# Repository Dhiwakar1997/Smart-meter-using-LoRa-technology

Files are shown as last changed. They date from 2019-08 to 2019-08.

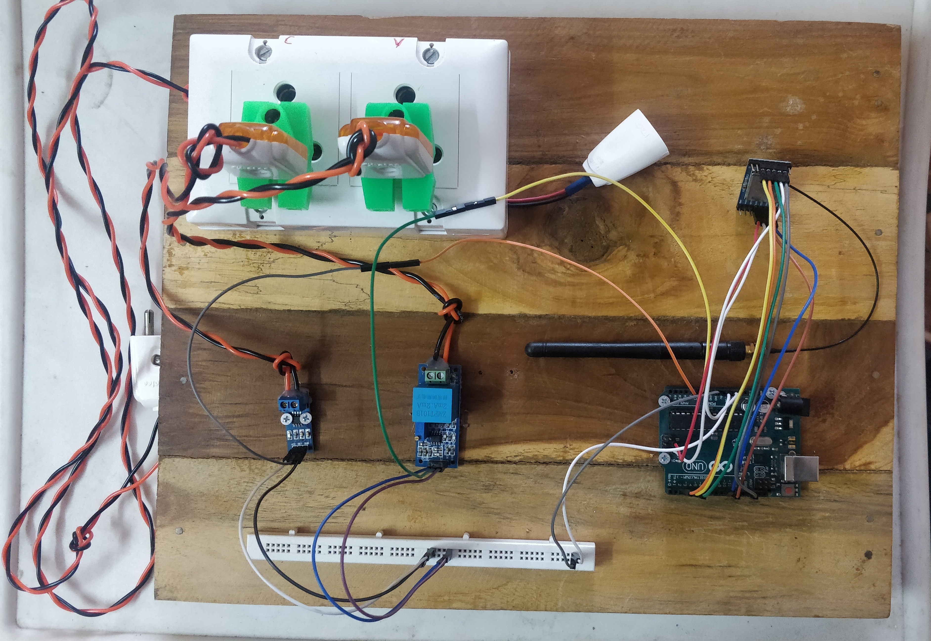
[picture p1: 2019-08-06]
implementation/LoRa based smart meter setup.jpg

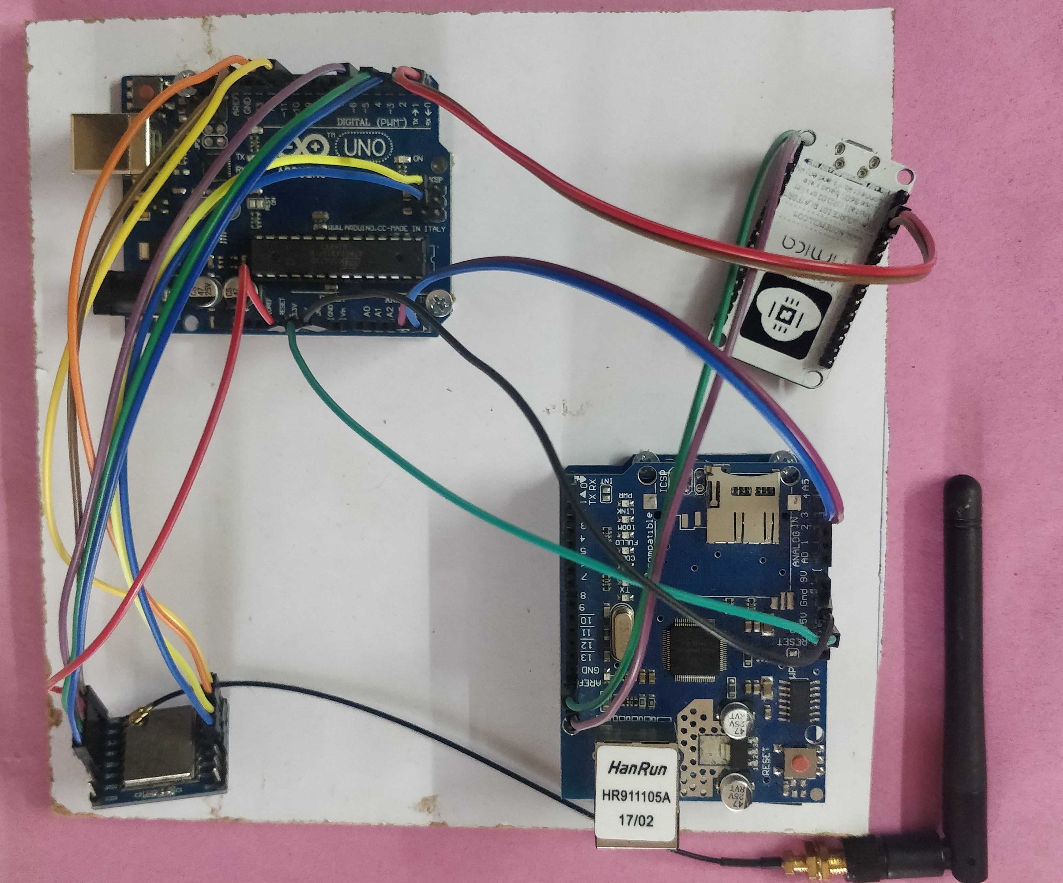
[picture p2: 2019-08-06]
implementation/gateway setup.jpg

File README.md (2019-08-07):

# Smart-meter-using-LoRa-technology
This is a smart energy meter project which measures the meter readings and visualizes the data live on a mobile application.
The main advantage of this project is that the project doesn't require an internet connection in the houses where the meter is installed.

Data is transferred wirelessly through LoRa wireless technology.

The project is divided into three phases:

1.LoRa based smart meter - It measures energy meter reading and transmits it wirelessly using LoRa.

2. LoRa receiver - It receives the LoRa signals form the meters.

3. Gateway with ethernet/Gateway with WiFi - Received data from LoRa receivers is transferred to a server through these gateways. 
                                             In this project two types of gateways are designed for flexibility,
                                             they are classified asGateway with ethernet & Gateway with WiFi.

Interfaces Used:
1.arduino is connected with LoRa transceivers using the SPI interface.

2. Arduino is connected to another Arduino using I2C interface.

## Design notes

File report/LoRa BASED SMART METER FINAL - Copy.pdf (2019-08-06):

# LoRa BASED SMART METER FOR RURAL AREAS WITHOUT INTERNET

## TABLE OF CONTENTS

TITLE | PAGE NO.
ABSTRACT | 7
LIST OF FIGURES | 8
LIST OF SYMBOLS | 9
1. INTRODUCTION | 10
1.1 CHAPTER INTRODUCTION | 10
1.2 INTRODUCTION TO LoRa BASED SMART METER | 10

FOR RURAL AREAS WITHOUT INTERNET

1.3 LITERATURE SURVEY | 11
1.4 SUMMARY | 14
2. INTERGRATION OF LoRa BASED SMART METER | 15

FOR REMOTE VILLAGES

2.1 CHAPTER INTRODUCTION | 15
2.2 NEED FOR LoRa BASED SMART METER IN | 15

REMOTE VILLAGE

2.3 IMPLEMENTATION OF LoRa BASED SMART | 16

METERS IN REMOTE VILLAGES

2.4 LoRa GATEWAY ENHANCEMENTS FOR REMOTE | 17

VILLAGES

2.5 ADVANTAGES OF LoRa BASED SMART METERS | 18

FOR REMOTE VILLAGES

2.6 SUMMARY | 18
3. HARDWARE IMPLEMENTATION OF SMART METER | 19
3.1 CHAPTER INTRODUCTION | 19
3.2 CONNECTION OF CT AND VT ACROSS THE LOAD | 20

3.3 SCHEMATIC DIAGRAM OF SMART ENERGY | 21

METER NODE

3.4 SCHEMATIC DIAGRAM OF GATEWAY USING | 23

ETHERNET

3.5 SCHEMATIC DIAGRAM OF GATEWAY USING Wi-Fi | 25
3.6 HARDWARE DESCRIPTION | 27
3.6.1 CURRENT SENSOR | 27
3.6.2 VOLTAGE SENSOR | 28
3.6.3 ARDUINO UNO | 30
3.6.4 ETHERNET SHIELD | 32
3.6.5 NODE MCU | 32
3.7 SUMMARY | 33
4. SOFTWARE IMPLEMENTATION | 34
4.1 CHAPTER INTRODUCTION | 34
4.2 SMART ENERGY METER NODE | 35
4.2.1 FLOWCHART | 35
4.2.2 ALGORITHM | 36
4.2.3 PROGRAM | 36
4.3 LoRa RECEIVER | 40
4.3.1 FLOWCHART | 40
4.3.2 ALGORITHM | 41
4.3.3 PROGRAM | 41
4.4 GATEWAY USING ETHERNET | 44
4.4.1 FLOWCHART | 44
4.4.2 ALGORITHM | 45
4.4.3 PROGRAM | 45
4.5 GATEWAY USING NODE MCU ESP8266 | 49

4.5.1 FLOWCHART | 49
4.5.2 ALGORITHM | 50
4.5.3 PROGRAM | 50
4.6 BLYNK MOBLIE APP | 55
4.7 SUMMARY | 56
5. CONCLUSION | 57
5.1 CHAPTERS OVERVIEW | 57
5.1.1 CHAPTER 1 OVERVIEW | 57
5.1.2 CHAPTER 2 OVERVIEW | 57
5.1.3 CHAPTER 3 OVERVIEW | 58
5.1.4 CHAPTER 4 OVERVIEW | 58
5.2 ENERGY METER MODULE | 59
5.3 LoRa GATEWAY MODULE | 60
5.4 FINAL CONCLUSION | 61
6. REFERENCE | 62

ABSTRACT

This project is all about creating a simple and effective way to transmit

the meter reading to the electricity board automatically by using IOT without any

intervention of humans. The project uses LoRa transceiver to transmit the data

from each house to the LoRa gateway from which the data is transmitted through

the internet to the electricity board server. This project is more cost effective than

any of the competitive projects on the same field. By automation of these energy

meters man power is saved in very large scale. By this project false reading can

be avoided. The LoRa transceivers used in this project has a very long range and

designed for transmitting small but essential data through long distance. The

smart meter consist of its own voltage and current sensors which will provide

essential data to calculate the power consumed by the consumer. This power data

is transmitted in real time to a LoRa gateway from which data is transmitted to

electricity board through internet. The main advantage of this project is the data

is transmitted in real time with lowest cost. The infrastructure developed for this

smart meter will open up opportunities for much wider industries to start. The

project can provide the infrastructure needed for government to monitor

electricity theft in future updates. In future updates using the same infrastructure,

location systems can be built as alternative for GPS in cities where these smart

meters are installed. This project is sponsored by IEDC

## LIST OF FIGURES

FIGURE NO. | DETAILS | PAGE NO.
2.1 | Block diagram of data flow | 17
3.1 | Connection of CT and VT | 20
3.2 | Smart energy meter node | 21
3.3 | Gateway using ethernet | 23
3.4 | Gateway using wi-fi | 25
3.5 | Current sensor | 27
3.6 | Pin diagram | 28
3.7 | Voltage sensor | 28
3.8 | Pin diagram | 29
3.9 | Arduino Uno | 30
3.10 | Ethernet shield | 32
3.11 | Node MCU | 33
4.1 | Flowchart of smart energy meter node | 35
4.2 | Flowchart of LoRa receiver | 40
4.3 | Flowchart of gateway using Ethernet | 44
4.4 | Flowchart of gateway using Node MCU | 49
4.5 | Mobile app screenshot | 55
5.1 | Energy meter module | 59
5.2 | Circuit box | 59
5.3 | LoRa gateway module | 60

## LIST OF SYMBOLS

SYMBOLS | EXPLANATION
V | Voltage
I | Ampere
W | power

## CHAPTER 1

INTRODUCTION

### 1.1 CHAPTER INTRODUCTION

This chapter gives a brief introduction about the LoRa technology used

in this project. This chapter explains about the main aim of the project and also

discuses about use of smart energy meters. Though this chapter a brief

explanation about the working of the LoRa based smart energy meter is

explained. In this chapter [1.3] literature survey displays few IEEE reference

papers. These reference papers provided required knowledge to build this project

“LoRa based smart meter for rural areas without internet”

### 1.2 INTRODUCTION TO LoRa BASED SMART METER FOR RURAL

AREAS WITHOUT INTERNET

The LoRa based smart meter is all about creating a simple and

effective way to transmit the meter reading from household energy meters to the

electricity board automatically by using IOT without any intervention of humans.

The project uses LoRa transceiver to transmit the data from each house to a LoRa

gateway from which the data is transmitted through internet to the electricity

board server. This project is more cost effective than any of the competitive

projects on the same field. By automation of these energy meters man power is

saved in a very large scale. By this project false readings can be avoided. The

LoRa transceivers used in this project has a very long range and designed for

transmitting small but essential data through long distance.

The smart meter consists of its own voltage and current sensors which

will provide essential data to calculate the power consumed by the consumer.

This power data is transmitted in real time to a LoRa gateway from which data is

transmitted to electricity board server through internet. The main advantage of this project is that the data is transmitted in real time with lowest cost. The project

can provide the infrastructure needed for government to monitor electricity theft

in future updates. In future, updates using the same infrastructure, location

systems can be built as alternative for GPS in cities where these smart meters are

installed.

### 1.3 LITERATURE SURVEY

Visalatchi Senthilnathan , Kamal Sandeep Karreddula (2017)

declare in their research that Energy theft is a very common problem in countries

like India where consumers of energy are increasing consistently as the

population increases. Utilities in electricity system are destroying the amounts of

revenue each year due to energy theft. The newly designed AMR used for energy

measurements reveal the concept and working of new automated power metering

system but this increased the Electricity theft forms administrative losses because

of not regular interval checkout at the consumer's residence. It is quite impossible

to check and solve out theft by going every customer's door to door. In this paper,

a new procedure is followed based on MICROCONTROLLER Atmega328P to

detect and control the energy meter from power theft and solve it by remotely

disconnect and reconnecting the service (line) of a particular consumer. An SMS

will be sent automatically to the utility central server through GSM module

whenever unauthorized activities detected and a separate message will send back

to the microcontroller in order to disconnect the unauthorized supply. A unique

method is implemented by interspersed the GSM feature into smart meters with

Solid state relay to deal with the non-technical losses, billing difficulties, and

voltage fluctuation complication.

Gunawan Wibisono, Gilang Permata Saktiaji, Ihsan Ibrahim (2017)

researched Traditional electricity meters read manually, large workloads, major

errors and distributed at different installation locations, need to spend a lot of time

and labor costs. In real-time, the accuracy and extension of the application cannot be fulfilled. With technological developments, electric meters now can be used

both ways, for real-time remote reading, and can be used as prepaid and postpaid,

making it smart meter. Currently the smart meter has become an important part

of the smart grid system. Therefore, the national power utility company (PLN)

Bali region decided to replace the existing meter with smart meter to support Bali

Eco Smart Grid. Long Range (LoRa) wide area network (WAN) is the access

technology that used for implementing smart meter because it has benefits

including can reach long distance, low power, and lower cost. This study aims to

analyze the techno economic smart meter 2 ways implementation at Bali region

by using techno-economic method and cost-benefit analysis. In addition to

analyze technological and economic aspects, the business model and the

regulatory aspect analysis are also included. The results show that LoRa WAN is

one of the technology options that can be used today, the business model that can

be used is build own or implementation is done by itself, build operate transfer

(BOT) or outsourcing to third party, and rental model. According the ministry of

communication and information regulation number 35/2015, LoRa WAN that

operate at frequencies 923-925 MHz can be implemented to support smart meter

implementation by Bali PLN.

Tian | Xia , (https://ieeexplore.ieee.org/author/37086562442) Cencen | Liu , (https://ieeexplore.ieee.org/author/37086563640) Xin | Zheng , (https://ieeexplore.ieee.org/author/37086557094) Ming | Lei , (https://ieeexplore.ieee.org/author/37086555833) Shangpeng
Wang , (https://ieeexplore.ieee.org/author/37086560597) Yingchun Wang,(2018) (https://ieeexplore.ieee.org/author/37086560953) developed | The principle of field testing for

digital electric energy meters is analyzed, according to which a digital reference

energy meter with high accuracy is developed based on high-precision frequency

division pulse output technology, algorithm of dot product sum of interpolation

re-sampling and high performance DSP. The test method based on the digital

reference meter is applied field testing comparing with a set of calibration system.

The results of the test prove high accuracy, efficiency and stability.

Win Hlaing ; (https://ieeexplore.ieee.org/author/37086219197) Somchai Thepphaeng ; (https://ieeexplore.ieee.org/author/37071208000) Varunyou Nontaboot ; (https://ieeexplore.ieee.org/author/37086216367)

Natthanan Tangsunantham ; (https://ieeexplore.ieee.org/author/37071583900) Tanayoot Sangsuwan ; (https://ieeexplore.ieee.org/author/37085398100) Chaiyod Pira (https://ieeexplore.ieee.org/author/37086223524) (2017)

propose that the advent of Internet and computational era, not only opportunity

to send and receive data between humans, but also among the devices without

human control over it. This is known as Internet of Things (IoTs) concept which

can be applied for solving the growing issue of power/energy management. A

solution is a cheap and easy to implement and manage energy monitoring system

for our daily usage of electric power. In order to overcome the human errors,

manual labor and cost reducing in energy consumption with more efficiency for

the power management system, in this paper, we focus mainly on IoT's energy

monitoring. The proposed design is to implement a very low cost wireless sensor

network and protocol for smart energy and web application capable of

automatically reading the unit and sending the data automatically for the power

users to view their current energy meter reading. By using this system, the users

will be aware of the electricity usage in his/her home to reduce the power wastage

and cost of consumption. The system consists of a digital energy meter, ESP8266

WiFi module and web applications for management system. The ESP8266 WiFi

module will be embedded into the meter and implement the TCP/IP protocol for

the communications between the meter and web application. The experimental

results show that the proposed system works very well with efficiency, and it is

feasible to implement in practical applications for very low cost-build automatic

energy meter reading.

### 1.4 SUMMARY

This chapter gives a introduction to LoRa based smart meter for

rural areas without internet. It gives a brief knowledge about the project and it

helps in understanding the aim of the project. It also provides IEEE paper of

reference in 1.3 literature survey. These reference paper helps to improve the

understanding about the project and also helps to relate the technologies used in

this project to that technologies used in the reference papers.

## CHAPTER 2

### 2. INTEGRATION OF LoRa BASED SMART METER

FOR REMOTE VILLAGES

### 2.1 CHAPTER INTRODUCTION

This chapter discusses about integration of LoRa based smart meters in

rural areas i.e. remote villages. In this chapter we have discussed about the need

for LoRa based smart meters in remote villages in 2.1 need for lora based smart

meters in remote villages. The explanation given about the need of this project in

this chapter is based on the real time day to day conditions. It speaks about the

reality conditions and also proposes solutions to handle that situation. In 2.2

implementation of lora based smart meters in remote villages the ways to

implement the lora based smart meter is discussed. The block diagrams were

used to explain about the data flow starting from household smart meter to a EB

server. In this chapter 2.3 implementation of lora based smart meters in remote

villages explains about the innovations made in LoRa gateway technologies in

this project. It clearly states the major advantages of the innovation in LoRa

gateway technology. Through this chapter the needs and ways to accomplish

though needs is discussed. This chapter gives clear knowledge about the

implementation and advantages of such implementation of this project.

### 2.2 NEED FOR LORA BASED SMART METERS IN REMOTE

VILLAGES

Technologies are for everyone. For people in urban cities and also for

people living in rural areas. But as of today, conditions changed as if smart

technologies are only applicable for people living in cities and people living in rural areas are meant to live old life style. The main reason behind this, is that

urban areas have updated infrastructures like high speed internet connections and

lot more infrastructure to make their life easier but in remote villages these

infrastructures are not available. This makes developers to concentrate more on

projects based on city life style.

One among those projects is smart meter working with internet

connections. But these smart meters cannot be installed in remote villages as these

villages doesn’t have internet connection for every house. LoRa based smart

meters take the advantage in this point. These LoRa based smart meters doesn’t

require internet connection in every house. As these LoRa transceivers have a

maximum range up to 10Km the energy meter readings can be directly

transmitted from a LoRa node i.e. LoRa based smart energy meter and it can be

received by a LoRa receiver in the LoRa gateway.

### 2.3 IMPLEMENTATION OF LORA BASED SMART METERS

IN REMOTE VILLAGES.

Each energy meter is provided with a LoRa transceivers. This energy

meter setup acts as a LoRa node. Each LoRa node transmits energy meter reading

with the unique address of that particular node encrypted inside a string. This

string is received by the LoRa gateway and the data is uploaded to a server using

internet. In this method its enough to have internet connection only for the

gateway alone and there is no need to provide internet connection for each and

every houses.

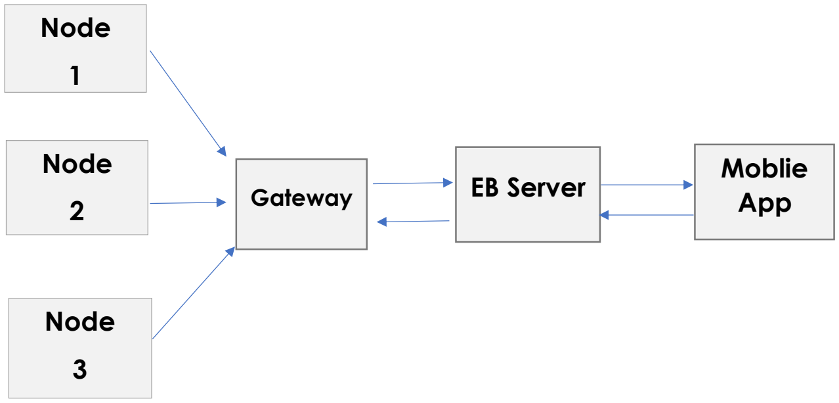
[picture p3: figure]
Node; Gateway; EB Server; Moblie; App

Fig 2.1 Block diagram of data flow

Node represents the smart energy meter fixed in every house. These

nodes are connected with LoRa gateway, and this gateway is connected to

internet. The gateways are programmed to receive energy meter readings from

the node and transmit to a EB server. This data can be retrieved from the server

and viewed using a mobile application. The mobile application receives the data

directly from the server.

### 2.4 LoRa GATEWAY ENHACEMENTS FOR REMOTE

VILLAGES

In general LoRa gateways are connected to internet using ethernet

cable. But when considering remote villages, even ethernet connections may not

be available in worst case scenarios. In this project we have come up with a

solution for this. The LoRa gateway that is designed for this project is compatible

with both ethernet cables as well as WiFi internet connections. The LoRa gateway

is connected to a WiFi module nodeMCU ESP8266 this enables LoRa gateway

to get connected with internet just with mobile hotspot connection. In real time

usage even a portable WiFi modem can be used to connect the LoRa gateway to

internet.

### 2.5 ADVANTAGES OF LoRa BASED SAMRT METERS FOR

REMOTE VILLAGES.

Illegal power tapping widely happen in remote villages. These illegal

power tapping can be easily identified using this LoRa based smart meter.

Every individual house is made accountable for their power usage as the whole

process is documented and digitalized. Form technical side, since villages

doesn’t have tall concrete walls and buildings to weaken the LoRa signal, in

these villages lesser number of gateways are enough to establish service when

compared to dense urban cities.

### 2.6 SUMMARY

This chapter discussed about the need for LoRa based smart meters in

remote villages. It also explained the implementation of LoRa based smart meters

in remote villages. The advantages of these smart meters specifically in remote

villages is detailly addressed here in this above chapter. This chapter also discuss

about the innovation made in LoRa gateway technology. It detailly informs about

the two major ways of implementation of LoRa gateway.

## CHAPTER 3

HARDWARE IMPLEMENTATION OF SMART METER

### 3.1 CHAPTER INTRODUCTION

This chapter discuss about the hardware implementation of smart meter. In

this chapter the circuit diagrams used in this project is detailly explained. These

circuit diagrams plays a major role in proper execution of this project. This

chapter is added with schematic diagrams with its explanations. These schematic

diagrams show cast the connections between the microcontrollers and other

sensors and transceivers. This would give a clear image about how the

components are connected with one another. These connections and explanations

also discus about the interface using which the components are connected with

one another. In this chapter each and every component used are explained in 3.5

hardware description. These details consist of key features of the components

with their specifications. By specifying the specification and key features of the

components knowledge about the nature of the components and their uses are

explained in this chapter.

### 3.1 CONNECTION OF CT AND VT ACROSS THE LOAD

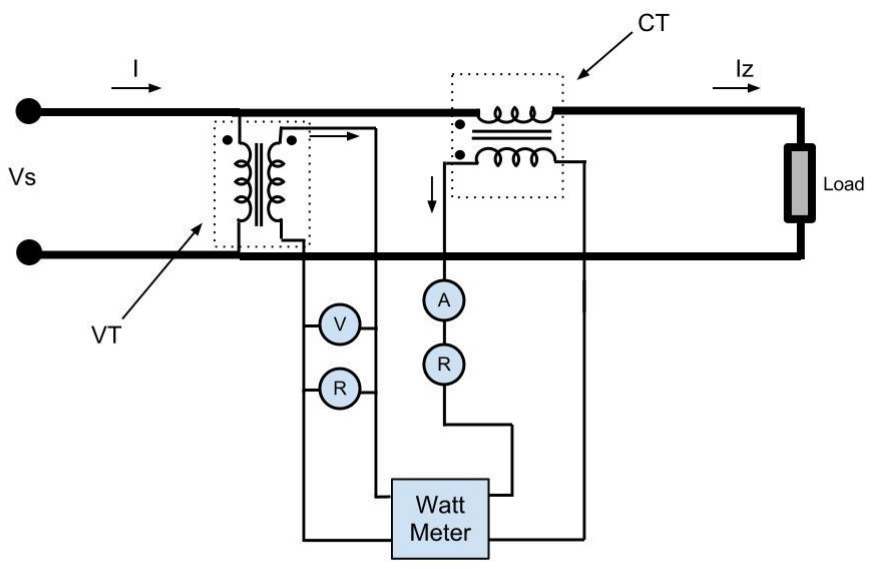
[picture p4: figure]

Fig 3.1 Connection of CT and VT

For transferring the power data value from each node there is a need to

measure the power data initially. For that purpose voltage and current are needed

to be measured. It is achieved by connecting the current sensor in series with load

and voltage sensor in parallel with load as described in circuit diagram. Here the

Arduino Uno acts as the wattmeter, which receives the sensor data from voltage

and current sensor and calculate watt and watt per hour data values.

### 3.2 SCHEMATIC DIAGRAM OF SMART ENERGY METER NODE

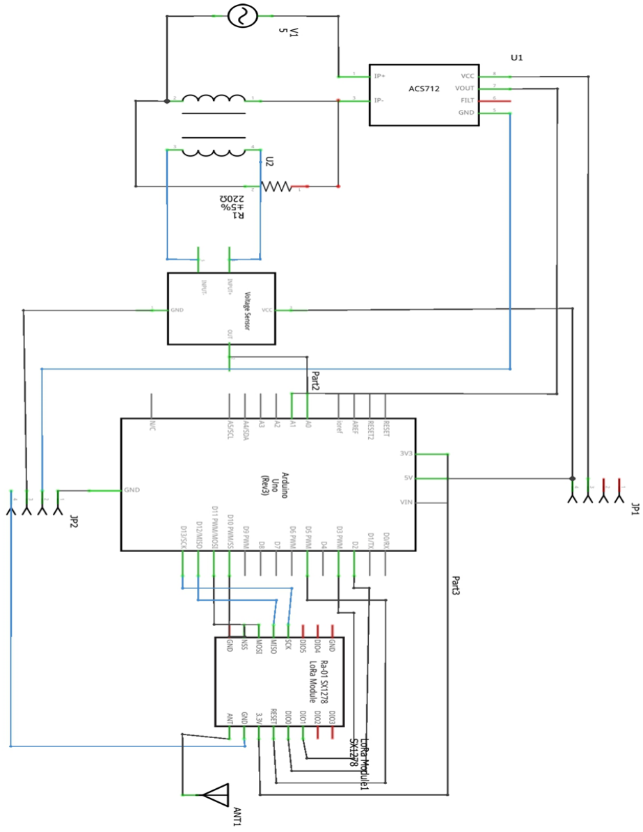
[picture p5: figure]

Fig 3.2 Smart energy meter node

EXPLANATION

In this phase energy meter is built and the microcontroller is

interfaced with the LoRa module SX1278. The schematic explains the way to

connect the current sensor ACS712 and voltage sensor across the load. The

voltage and current sensors are powered using +5 volt and Gnd of the Arduino

microcontroller. Two junctions are used to utilize the 5V and ground of the

Arduino to power multiple sensors connected to it. The voltage sensor is

connected to Analog pin A0 of the Arduino microcontroller. Current sensor is

connected to analog pin A1 of the Arduino microcontroller. The LoRa module

SX1278 is interfaced with Arduino microcontroller using Serial Peripheral

Interface (SPI). LoRa module is connected to an antenna of 5dB gain.

### 3.3 SCHEMATIC DIAGRAM OF GATEWAY USING ETHERNET

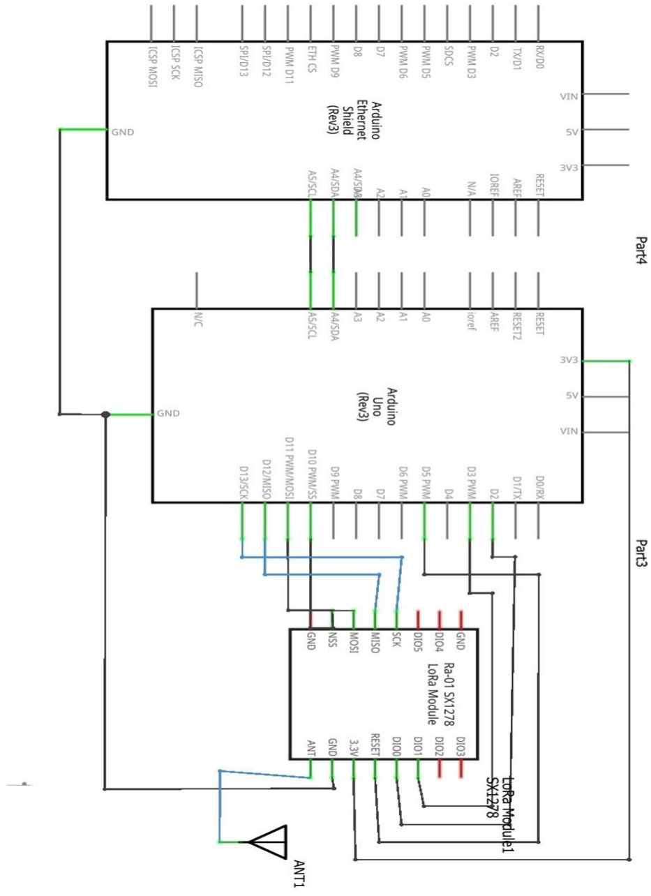
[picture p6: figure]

Fig 3.3 Gateway using ethernet

EXPLANATION

The schematic explains how the ethernet shield is connected to

LoRa receiver. The LoRa receiver by itself is connected to an Arduino Uno and

this Arduino is connected to an Ethernet shield using I2C interface. The LoRa

module SX1278 is interfaced with Arduino microcontroller using Serial

Peripheral Interface(SPI). LoRa module is connected to an antenna of 5dB gain.

The ethernet shield is connected to internet via fibre optic cables. The ethernet

shield is grounded through Arduino Uno. The LoRa module is powered by the

Arduino microcontroller.

### 3.5 SCHEMATIC DIAGRAM OF GATEWAY USING Wi-Fi

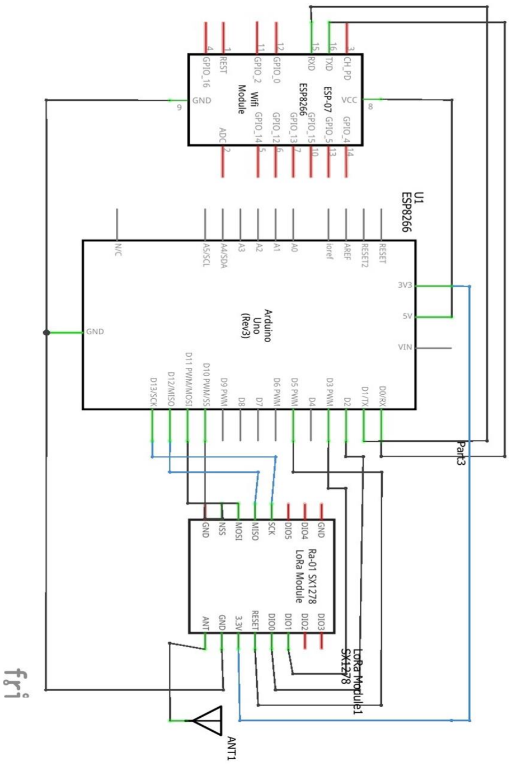
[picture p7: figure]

Fig 3.4 Gateway using wi-fi

EXPLANATION

The schematic explains how the node MCU ESP8266 is connected

to LoRa receiver. The LoRa receiver by itself is connected to an Arduino Uno

and this Arduino is connected to an node MCU ESP8266 using serial Tx and Rx

ports. The LoRa module SX1278 is interfaced with Arduino microcontroller

using Serial Peripheral Interface (SPI). LoRa module is connected to an antenna

of 5dB gain. The node MCU ESP8266 is connected to internet via Wi-Fi. The

node MCU ESP8266 is grounded through Arduino Uno. The LoRa module is

powered by the Arduino microcontroller.

### 3.6 HARDWARE DESCRIPTION

### 3.6.1 CURRENT SENSOR – ACS712

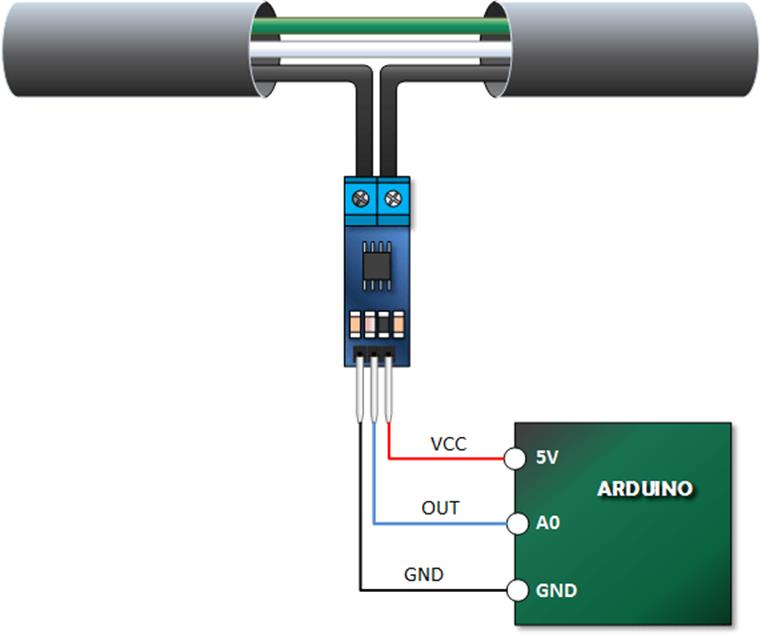
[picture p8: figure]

Fig 3.5 Current sensor

The Allegro® ACS712 provides economical and precise

solutions for AC or DC current sensing in industrial, automotive,

commercial, and communications systems. The device package allows for

easy implementation by the customer. Typical applications include motor

control, load detection and management, switched-mode power supplies,

and overcurrent fault protection.

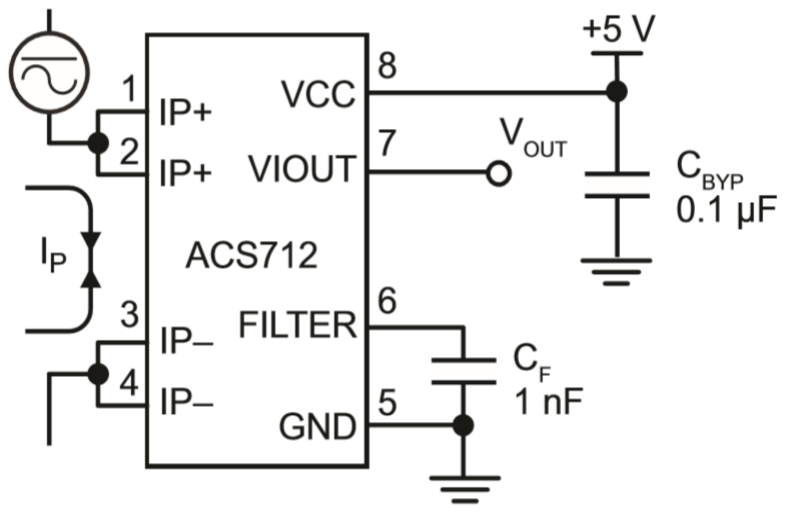
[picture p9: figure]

Fig 3.6 Pin diagram

KEY FEATURES

- Low-noise analog signal path
- Total output error 1.5% at TA = 25°C, and 4% at –40°C to 85°C
- 1.2 mΩ internal conductor resistance
- Output voltage proportional to AC or DC currents

Extremely stable output offset voltage

### 3.6.2 VOLTAGE SENSOR – ZMPT101B

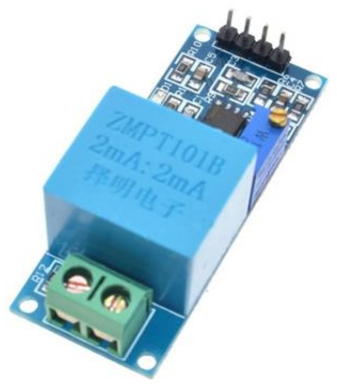
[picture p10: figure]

Fig 3.7 voltage sensor

ZMPT101B voltage sensor module is a voltage sensor made from the

ZMPT101B voltage transformer. It has high accuracy, good consistency for

voltage and power measurement and it can measure up to 250V AC. It is simple

to use and comes with a multi turn trim potentiometer for adjusting the ADC

output. The analysis in this paper tends to find more accurate relationship between

the input voltage and the ADC output by regression analysis. The ADC output is

adjusted using the trimpot to an appropriate value against a reference input.

Figure-1 is the ZMPT101B voltage sensor module.

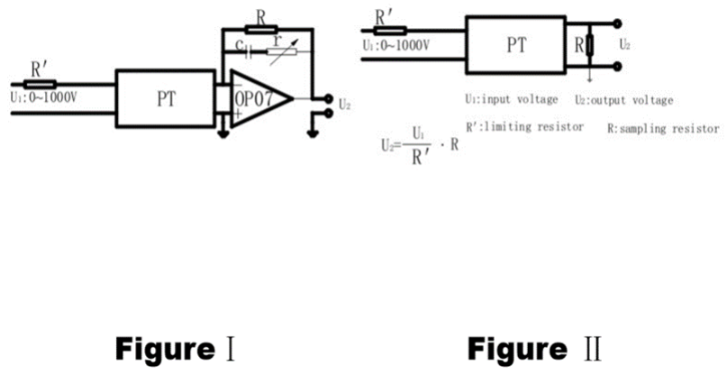
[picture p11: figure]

Fig 3.8 Pin diagram

KEY FEATURES

- Voltage upto 250 volts can be measured
- Light weight with on-board micro-precision voltage transformer
- High precision on-board op-amp circuit
- Operating temperature: 40ºC ~ + 70ºC
- Good consistency, for voltage and power measurement
- Very efficient and accuracy

### 3.6.3 ARDUINO UNO

The Arduino UNO is an open-source microcontroller board based

on the Microchip (https://en.wikipedia.org/wiki/Microchip_Technology) ATmega328P (https://en.wikipedia.org/wiki/ATmega328P) microcontroller and developed by

Arduino.cc. (https://en.wikipedia.org/wiki/Arduino) The board is equipped with sets of digital and analog

input/output (I/O) pins that may be interfaced to various expansion boards

(shields) and other circuits.

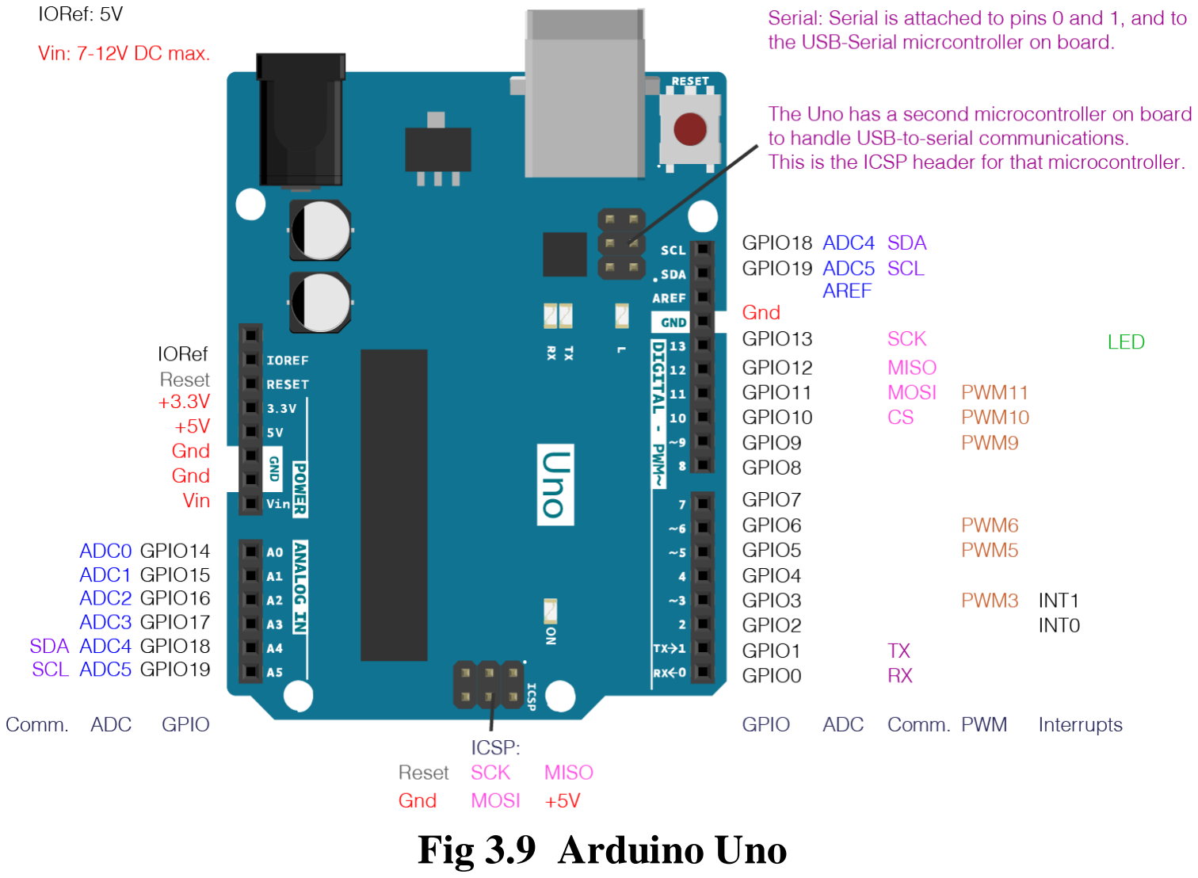
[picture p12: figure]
Fig 3.9 Arduino Uno

KEY FEATURES

- Microcontroller: ATmega328
- Operating Voltage: 5V
- Input Voltage (recommended): 7-12V
- Input Voltage (limits): 6-20V
- Digital I/O Pins: 14 (of which 6 provide PWM output)
- Analog Input Pins: 6

- DC Current per I/O Pin: 40 mA
- DC Current for 3.3V Pin: 50 mA
- Flash Memory: 32 KB of which 0.5 KB used by bootloader
- SRAM: 2 KB (ATmega328)
- EEPROM: 1 KB (ATmega328)
- Clock Speed: 16 MHz

The Arduino Uno is a microcontroller board based on the

ATmega328. Arduino is an open-source, prototyping platform and its

simplicity makes it ideal for hobbyists to use as well as professionals. The

Arduino Uno has 14 digital input/output pins (of which 6 can be used as

PWM outputs), 6 analog inputs, a 16 MHz crystal oscillator, a USB

connection, a power jack, an ICSP header, and a reset button. It contains

everything needed to support the microcontroller; simply connect it to a

computer with a USB cable or power it with a AC-to-DC adapter or battery

to get started.

### 3.6.4 ETHERNET SHIELD

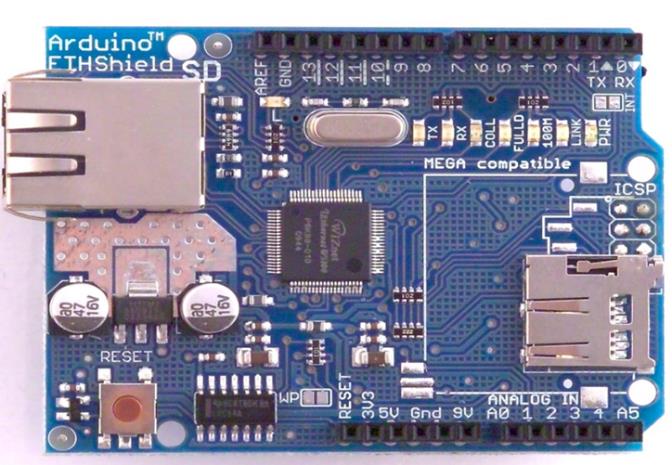
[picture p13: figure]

Fig 3.10 Ethernet shield

The ethernet shield is used to connect the Arduino Uno with

internet using fibre optic cables. It acts as the interface between Arduino

Uno and fibre optic cables.

### 3.6.5 NODE MCU ESP8266

The ESP8266 is a low cost MCU with built in Wi-Fi. It can be

paired with another host microcontroller, like an Arduino, to provide WiFi

networking | capability | for a | basic | IoT | development | platform.

Additionally, the ESP8266 can be used as a stand-alone MCU, as it

includes a 32-bit 80Mhz processor, 16 GPIO pins (4 PWM enabled) and a

built in Analog-to-Digital converter, SPI and I2C interfaces and more…

The MCU has a n operating voltage of 2.5V – 3.6V and average operating

current of 80 mA. Here is the official ESP8266 MCU datasheet (https://espressif.com/sites/default/files/documentation/0a-esp8266ex_datasheet_en.pdf) from the

Shangai -based manufacturer of the chip Express. The most popular

current version is the ESP-12E MCU pictured below. On its own this is not

very friendly for prototyping, as the spacing of the pins is not compatible

with standard headers and breadboards

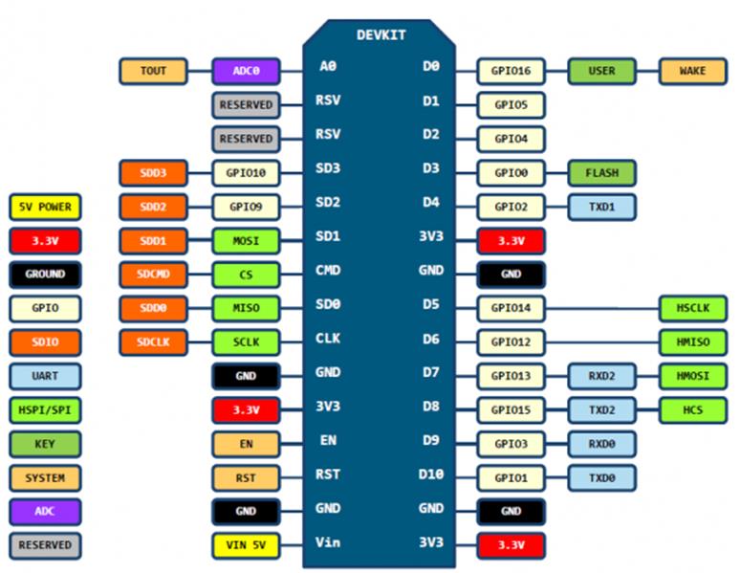
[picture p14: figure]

Fig 3.11 Node MCU

### 3.7 SUMMARY

This chapter clearly explained about the hardware

implementation and circuits used in this project. This chapter consists

of schematic diagrams and their explanations. The schematic diagrams

show casted in this chapter clearly explained the pin to pin connection

between the Arduino microcontroller and other sensors and

transceivers. In this chapter the hardware implementations and

executions are discussed. This chapter discussed about the hardware

specifications of each and every components used in this project. This

specifications included the use of these components. It also discussed

about the key feature of each and every components. Though this

chapter a clear image of hardware implementation and wider

awareness about the use of the components and their specifications.

## CHAPTER 4

SOFTWARE IMPLEMENTATION

### 4.1 CHAPTER INTRODUCTION

When the hardware components and their connections between them

describes physical portion of the project, the softwares used and code written in

the microcontroller plays the digital part of the project. This software portion acts

as important part of the project. The software codeing written in microcontroller

is what makes the functions to be performed. To transmit or receive data using

LoRa as well as calculating power all of this is carried out only by programming

the microcontroller respectively.

The software used to code the microcontroller is Arduino IDE. It

uses ‘C++’ programming language to program the microcontroller. This chapter

consists flowcharts, algorithms and as well as programs. The flowchart is the

diagrammatic representation of the flow of the program. This chapter consists of

4 flowcharts which represents 4 different programs used in the project. Algorithm

are included in this chapter. These algorithms are used to explain the flowcharts.

Thus for the four flowcharts included in the project four respective algorithms are

included to explain these flowcharts.

The ‘C++’ programs are included in this chapter. As the

programs play a very important role in the working of the project it is included.

The programs are written with comment by the side of every important lines.

These comment lines are used for understanding the program

### 4.2 SMART ENERGY METER NODE

### 4.2.1 FLOWCHART

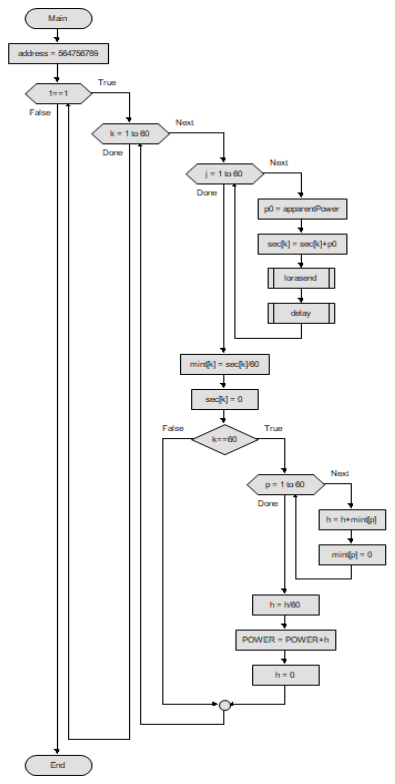
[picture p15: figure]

Fig 4.1 Flowchart of smart energy meter node

### 4.2.2 ALGORITHM

Step 1: Start.
Step 2: Create variables.
Step 3: Start of while loop.
Step 4: Start a for loop ‘k’ that increment every one minute for one hour and

Restart every hour.

step 5: Start a for loop ‘j’ that increment every one second for one minute and

restarts every minute.

Step 6: Calculates power value for that particular instance.
Step 7: Sum up the power values for one minute and store in a variable.
Step 8: Transmit the power value wirelessly through LoRa transceiver.
Step 9: Make delay for few milliseconds.
Step 10: Find the power value average and store it in a variable.
Step 11: If the for loop ‘k’ value is equal to ‘60’ continue else jump to step 4.
Step 12: Calculate watt/ hour value once an hour.
Step 13: Go to step 4.
Step 15: When for loop k terminates the command goes to while loop which is

infinite loop and program starts to run from step 4 again.

### 4.2.3 PROGRAM

#include <SPI.h> // 34rduino spi library

#include <LoRa.h> // 34rduino libraries ra02 lora

#include “EmonLib.h” | // Include Emon Library

EnergyMonitor emon1; | // Create an instance

float v=0;

float i=0;

float POWER=0,p0,h,sec[100],mint[100];

int counter=0,f=0;

char address[10]=”564756789”;

long start,esp;

void setup() {

Serial.begin(9600);

emon1.voltage(0, 380, 1.7); // Voltage: input pin, calibration, phase_shift

emon1.current(1, 10.8); // Current: input pin, calibration.

While (!Serial);

Serial.println(“LoRa Sender”);

if (!LoRa.begin(433E6)) {

Serial.println(“Starting LoRa failed!”);

while (1);

}

LoRa.setSpreadingFactor(10);

LoRa.setSignalBandwidth(62.5E3);

LoRa.crc();// put your setup code here, to run once

}

void loop() {

for(int k=1;k<=60;k++) // This loop increments every one minute

{

for(int j=1;j<=60;j++) // This loop increments every second

{

emon1.calcVI(20,2000); //POWER CALCULATION

float apparentPower = emon1.apparentPower; // deriving power value

p0=apparentPower;

if(p0<8)

p0=0;

sec[k]=sec[k]+p0; //sum up power value of every second for one minute

Serial.print(“Sending packet:”);// used for displaying the values

Serial.println(counter);

Serial.println(“power:”);

Serial.println(p0);

LoRa.beginPacket(); //LORA transnmission start

LoRa.print(POWER);

LoRa.print(‘$’);

LoRa.print(address);

LoRa.print(‘=’);

LoRa.print(p0);

LoRa.endPacket(); //LORA transmission end

counter++;

if(f==0)

{

delay(601); //delay for 601 millisecond

}

else

{

delay(592); // delay for 592 millisecond

f=0;

}

}

mint[k]=sec[k]/60; //takes average of power of one minute,stores in mint[k]

sec[k]=0; // set “sec[k]” to zero to make it empty for next loop cycle

if(k==60) // “k =60” for every one hour

{

for(int p=1;p<=60;p++) // this loop runs once an hour

{

h=h+mint[p]; //sum up the all minute values in “h”

mint[p]=0; // “mint[p]” is emptied for next loop cycle

}

h=h/60; // “h” is stroed with power average for one hour i.e. watt/hour

POWER=POWER+h; //unit value

Serial.println(POWER); //displaying power

Serial.println(“xxxxxxxxxxxxxxxxxxxxxxxxxxxx”);

h=0;// assigning “h” as zero

}

}

}

### 4.3 LoRa RECEIVER

### 4.3.1 FLOWCHART

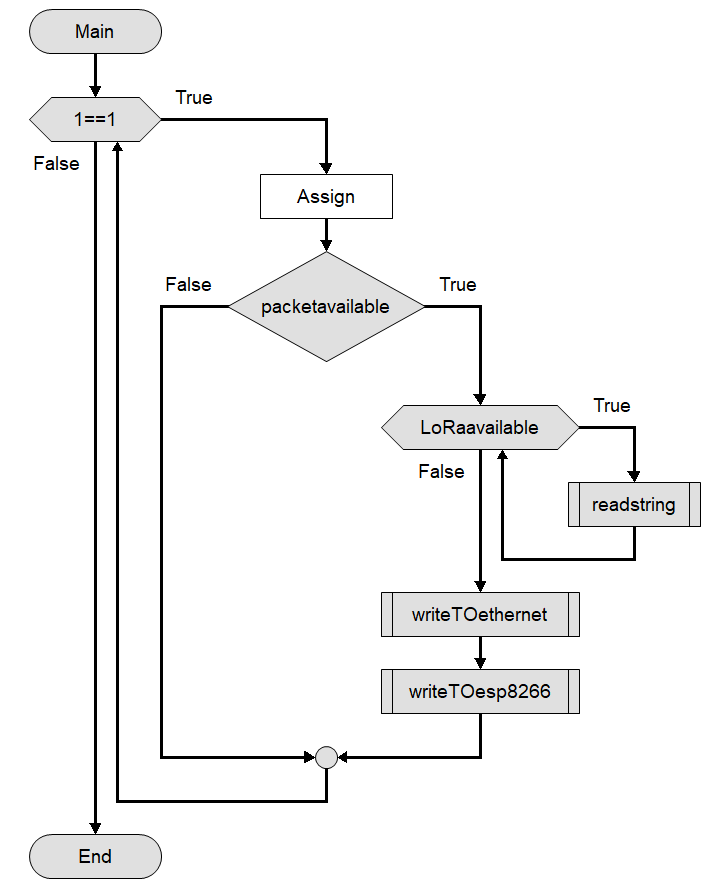
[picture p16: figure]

Fig 4.2 Flowchart of LoRa receiver

### 4.3.2 ALGORITHM

Step 1: Start.
Step 2: Start a while loop.
Step 3: Sariables are assigned.
Step 4: If LoRa signal is available the program continue else the program goes to
step 2.
Step 5: If a LoRa string in received the program continues else goes to step 2.
Step 6: Read the received string and save it in a variable.
Step 7: Write the saved variable to ethernet shield using I2C interface.
Step 8: Write the saved variable to ESP8266 using Tx & Rx serial ports.
Step 9: Goes to step 2 since the while loop used is a infinite loop.

### 4.3.3 PROGRAM

#include <SPI.h> // 39rduino spi library

#include <Wire.h>

#include <LoRa.h> // 39rduino libraries for ra02 lora

char val,l,ma,mystr,energy[20],address[20],watt[20];

char fullstr[30]=”123954x486y184u”;

int j1=0,j2=0,j3=0,i=0,x,t=0,f1=0,f2=0,p=0;

void setup() {

Serial.begin(9600);

Wire.begin(8); | // join i2c bus with address #8

while (!Serial);

Serial.println(“Lora Receiver”);

if (!LoRa.begin(433E6)) {

Serial.println(“Starting LoRa failed “);

}

LoRa.setSpreadingFactor(10);

LoRa.setSignalBandwidth(62.5E3);

LoRa.crc();

}

void loop()

{

int packetSize = LoRa.parsePacket();

if (packetSize) { // read packet

int i=0;

t=0;

j1=0;

j2=0;

j3=0;

f1=0;

f2=0;

while (LoRa.available()) //finds signal available or not

{

mystr=(char)LoRa.read();// read data character by character

fullstr[i++]=mystr; //store the character as string in “fullstr”

if(mystr==’$’)

{

f1=1;

continue;

}

else if(mystr==’=’)

{

f2=1;

continue;

}

if(f1==0&&f2==0) //splitting “energy”

energy[j1++]=mystr;

else if(f2==1&&f1==1) //splitting “watt”

watt[j2++]=mystr;

else //splitting “address”

address[j3++]=mystr;

}

x=strlen(energy);

Serial.println(“”);

Serial.print(“ADDRESS:”);

Serial.println(address);

Serial.print(“ENERGY:”);

Serial.println(energy);

Serial.print(“WATT/HR:”);

Serial.println(watt);

Wire.beginTransmission(8); // transmit to device #8 to ethernet

Wire.write(fullstr);

Wire.write(“ “);

Wire.endTransmission(); // stop transmitting to ethernet

Serial.write(fullstr,30); // transmitting to ESP8266

}}

### 4.4 GATEWAY USING ETHERNET

### 4.4.1 FLOWCHART

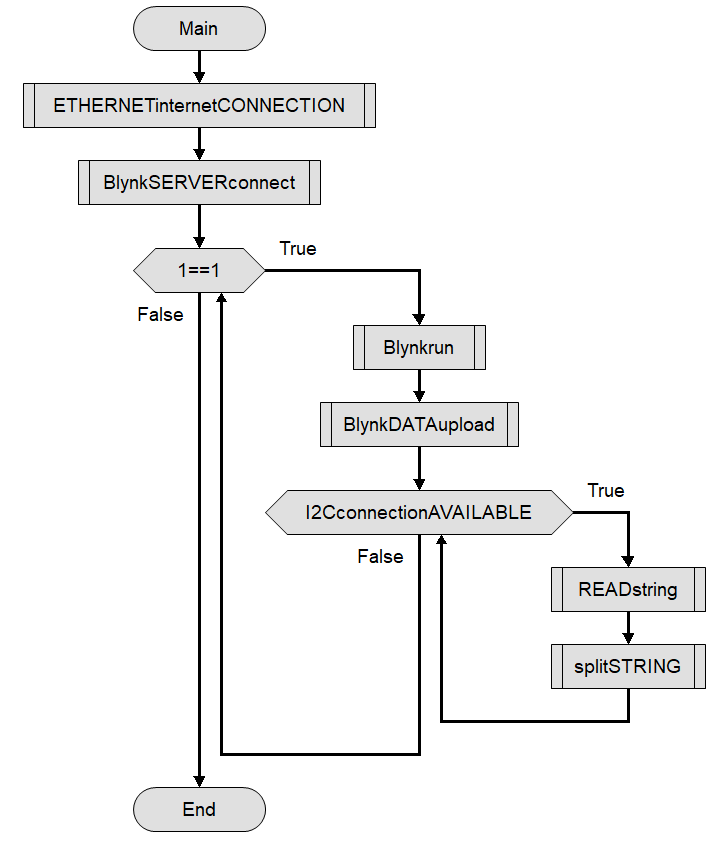
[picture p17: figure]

Fig 4.3 Flowchart of gateway using ethernet

### 4.4.2 ALGORITHM

Step 1: Start.
Step 2: Connects to internet through ethernet shield.
Step 3: Connect to Blynk server.
Step 4: Start a while loop.
Step 5: Run the blynk library.
Step 6: Upload the variable to blynk server.
Step 7: If connection available I2C interface program continues

else go to step 4

Step 8: Read the variable from I2C connection and save it in a variable.
Step 9: Split the received string.
Step 10: Goes to step 4 and the while loop run again and again since it is a

Infinite loop.

### 4.4.3 PROGRAM

#define BLYNK_PRINT Serial

#include <Wire.h>

#include <SPI.h>

#include <Ethernet.h>

#include <BlynkSimpleEthernet.h>

// You should get Auth Token in the Blynk App.

// Go to the Project Settings (nut icon).

Char auth[] = “6ec4b4c46e77464f8e0c2a9908e95993”;

#define W5100_CS 10

#define SDCARD_CS 4

// DHT 11

//#define DHTTYPE DHT22 // DHT 22, AM2302, AM2321

//#define DHTTYPE DHT21 // DHT 21, AM2301

BlynkTimer timer; // creating object for blynk

char mystr[20],energy[20],address[20],watt[20];

int j1=0,j2=0,j3=0,i=0,x,t=0,f1=0,f2=0,p=0;

// This function sends Arduino’s up time every second to Virtual Pin

(5).

// In the app, Widget’s reading frequency should be set to PUSH.

This means

// that you define how often to send data to Blynk App.

Void sendSensor()

{

char val[20]=””;

for(int j=0;j<i;j++)

{

val[j] =mystr[j];

}

// Serial.println(i);

Serial.println(val);

Blynk.virtualWrite(V1, watt); //uploading to server

Blynk.virtualWrite(V0, energy); //uploading to server

Blynk.virtualWrite(V2, address); //uploading to server

strcpy(mystr,””);//empty “mystr”

}

void setup()

{

// Debug console

Wire.begin(8); | // join i2c bus with address #8

Wire.onReceive(receiveEvent); // register event

Serial.begin(9600); | // start serial for output

pinMode(SDCARD_CS, OUTPUT);

digitalWrite(SDCARD_CS, HIGH); // Deselect the SD card

Blynk.begin(auth);

// You can also specify server:

//Blynk.begin(auth, “blynk-cloud.com”, 80);

//Blynk.begin(auth, IPAddress(192,168,1,100), 8080);

// Setup a function to be called every second

timer.setInterval(1000L, sendSensor);

}

void loop()

{

Blynk.run();

timer.run();

i=0;

t=0;

j1=0;

j2=0;

j3=0;

f1=0;

f2=0;

while (1 < Wire.available()) { // loop through all but the last

char mystr = Wire.read(); // receive byte as a character

if(mystr==’$’)

{

f1=1;

continue;

}

else if(mystr==’=’)

{

f2=1;

continue; }

//Serial.print(mystr);

if(f1==0&&f2==0) // split “energy” from “mystr”

energy[j1++]=mystr;

else if(f2==1&&f1==1) //split “watt” from “mystr”

watt[j2++]=mystr;

else // split “address” from “mystr”

address[j3++]=mystr;

}

int x; // receive byte as an integer

x = Wire.read();

Serial.println(address);

Serial.println(watt);

Serial.println(energy);

delay(500);

}

void receiveEvent(int howMany)

{ | }

### 4.5 GATEWAY USING NODE MCU ESP8266

### 4.5.1 FLOWCHART

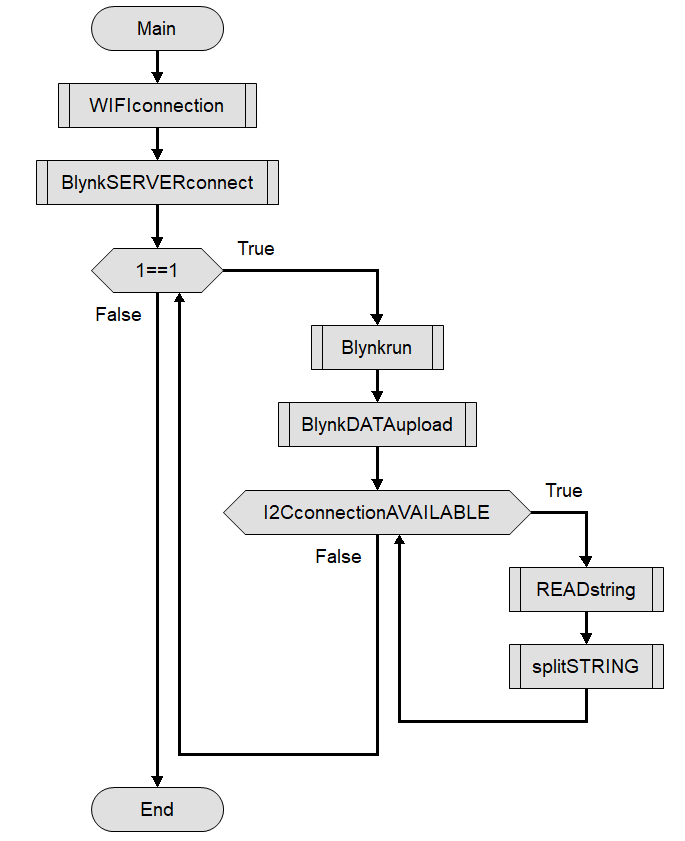
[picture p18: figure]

Fig 4.4 Flowchart of gateway using Node MCU

### 4.5.2 ALGORITHM

Step 1: Start.
Step 2: Connects to internet through Wi-Fi.
Step 3: Connect to Blynk server.
Step 4: Start a while loop.
Step 5: Run the blynk library.
Step 6: Upload the variable to blynk server.
Step 7: If connection available I2C interface program continues

else go to step 4.

Step 8: Read the variable from I2C connection and save it in a variable.
Step 9: Split the received string.
Step 10: Goes to step 4 and the while loop run again and again since it is a

Infinite loop.

### 4.5.3 PROGRAM

#define BLYNK_PRINT Serial

#include <ESP8266WiFi.h>

#include <BlynkSimpleEsp8266.h>

// You should get Auth Token in the Blynk App.

// Go to the Project Settings (nut icon).

char auth[] = "9c0f15fc9db146f19808881e9fdc4611";

// Your WiFi credentials.

// Set password to "" for open networks.

char ssid[] = "lone";

char pass[] = "12345678";

char mystr[20];

BlynkTimer timer;

char energy[20],address[20],watt[20];

int far,h,po=0,f3=0,j2=0,j3=0,i=0,x,t=0,f1=0,f2=0,p=0;

void sendSensor()

{

char val[20]="";

for(int j=0;j<i;j++)

{

val[j] =mystr[j];

}

//Serial.println(i);

Blynk.virtualWrite(V0, address); //uploading to server

Blynk.virtualWrite(V1, watt); //uploading to server

Blynk.virtualWrite(V2,energy ); //uploading to server

strcpy(mystr,"");//empty mystr

}

void setup()

{

// Debug console

Serial.begin(9600);

Blynk.begin(auth, ssid, pass);

timer.setInterval(1000L, sendSensor);

// You can also specify server:

//Blynk.begin(auth, ssid, pass, "blynk-cloud.com", 80);

//Blynk.begin(auth, ssid, pass, IPAddress(192,168,1,100), 8080);

}

void loop()

{

Blynk.run();

timer.run();

Serial.readBytes(mystr,30); //Read the serial data and store in “mystr”

// Serial.println(mystr); //Print data on Serial Monitor

far=strlen(mystr);

// Serial.println(far);

i=0;

t=0;

po=0;

j2=0;

j3=0;

f1=0;

f2=0;

f3=0;

for(int h=0;h<far;h++)

{

if(mystr[h]=='$')

{

f1=1;

continue;

}

else if(mystr[h]=='=')

{

f2=1;

continue;

}

if(mystr=="%")

f3=1;

if(f1==0&&f2==0)

{

address[po++]=mystr[h];

}

else if(f1==1&&f2==0)

{

watt[j3++]=mystr[h];

}

else

{

energy[j2++]=mystr[h];

}

}

Serial.print("ADDRESS:");

Serial.println(address);

Serial.print("WATT:");

Serial.println(watt);

Serial.print("ENERGY:");

Serial.println(energy);

}

### 4.6 BLYNK MOBILE APP

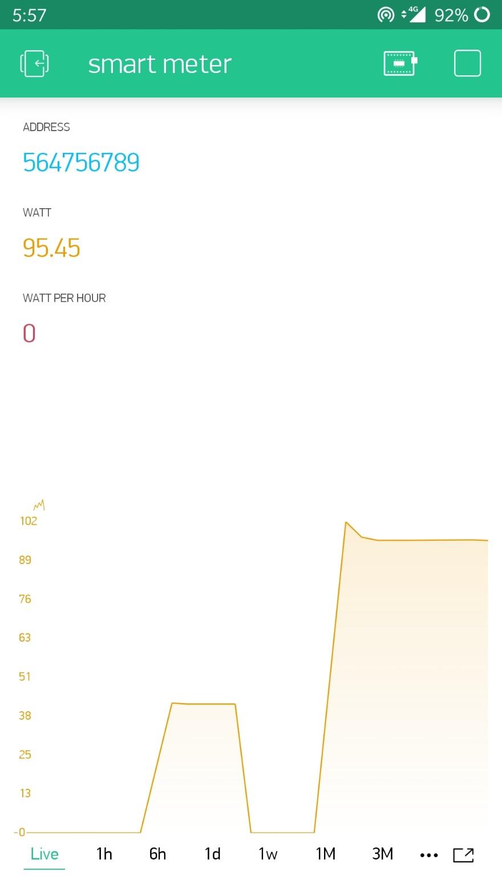
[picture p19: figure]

Fig 4.5 Mobile app screenshot

This is a mobile application developed for this project.

Through this application the power flowing the load can be view in real time. In

this application the mac address of the device can be viewed and as well as the

power consumed in by the consumer can also be viewed in real time.

### 4.7 SUMMERY

This chapter explains the software process carried out in this project.

It provides a view about how the programs function and it also helps to picturize

the working of the project. It explains the use and funcsioning of each

components in the project. In this chapter flowcharts are used to explain the

functioning of the program. In these flowcharts working of the loops used in the

program is represented diagrammatically. This chapter consist of algorithms for

understanding of the flowcharts. This chapter is also provided with the

programs used in the project. These programs are provided with comments by

its side. The comments are included in important lines. These comment line

explains the function of that particular line. In this chapter the screenshots of

the app developed for this project is show casted.

## CHAPTER 5

CONCLUSION

### 5.1 CHAPTERS OVERVIEW

### 5.1.1 CHAPTER 1 OVERVIEW

This chapter gives a brief introduction about the LoRa technology used

in this project. This chapter explains about the main aim of the project and also

discuses about use of smart energy meters. Though this chapter a brief

explanation about the working of the LoRa based smart energy meter is

explained. In this chapter [1.3] literature survey displays few IEEE reference

papers. These reference papers provided required knowledge to build this project

“LoRa based smart meter for rural areas without internet”

### 5.1.2 CHAPTER 2 OVERVIEW

This chapter discusses about integration of LoRa based smart meters in

rural areas i.e. remote villages. In this chapter we have discussed about the need

for LoRa based smart meters in remote villages in 2.1 need for lora based smart

meters in remote villages. The explanation given about the need of this project in

this chapter is based on the real time day to day conditions. It speaks about the

reality conditions and also proposes solutions to handle that situation. In 2.2

implementation of lora based smart meters in remote villages the ways to

implement the lora based smart meter is discussed. The block diagrams were

used to explain about the data flow starting from household smart meter to a EB

server. In this chapter 2.3 implementation of lora based smart meters in remote

villages explains about the innovations made in LoRa gateway technologies in

this project. It clearly states the major advantages of the innovation in LoRa

gateway technology. Through this chapter the needs and ways to accomplish though needs is discussed. This chapter gives clear knowledge about the

implementation and advantages of such implementation of this project.

### 5.1.3 CHAPTER 3 OVERVIEW

This chapter discuss about the hardware implementation of smart

meter. In this chapter the circuit diagrams used in this project is detailly

explained. These circuit diagrams plays a major role in proper execution of this

project. This chapter is added with schematic diagrams with its explanations.

These schematic diagrams show cast the connections between the

microcontrollers and other sensors and transceivers. This would give a clear

image about how the components are connected with one another. These

connections and explanations also discus about the interface using which the

components are connected with one another. In this chapter each and every

component used are explained in 3.5 hardware description. These details consist

of key features of the components with their specifications. By specifying the

specification and key features of the components knowledge about the nature of

the components and their uses are explained in this chapter.

### 5.1.4 CHAPTER 4 OVERVIEW

This chapter explains the software process carried out in this project.

It provides a view about how the programs function and it also helps to picturize

the working of the project. It explains the use and functioning of each

components in the project. In this chapter flowcharts are used to explain the

functioning of the program. In these flowcharts working of the loops used in the

program is represented diagrammatically. This chapter consist of algorithms for

understanding of the flowcharts. This chapter is also provided with the

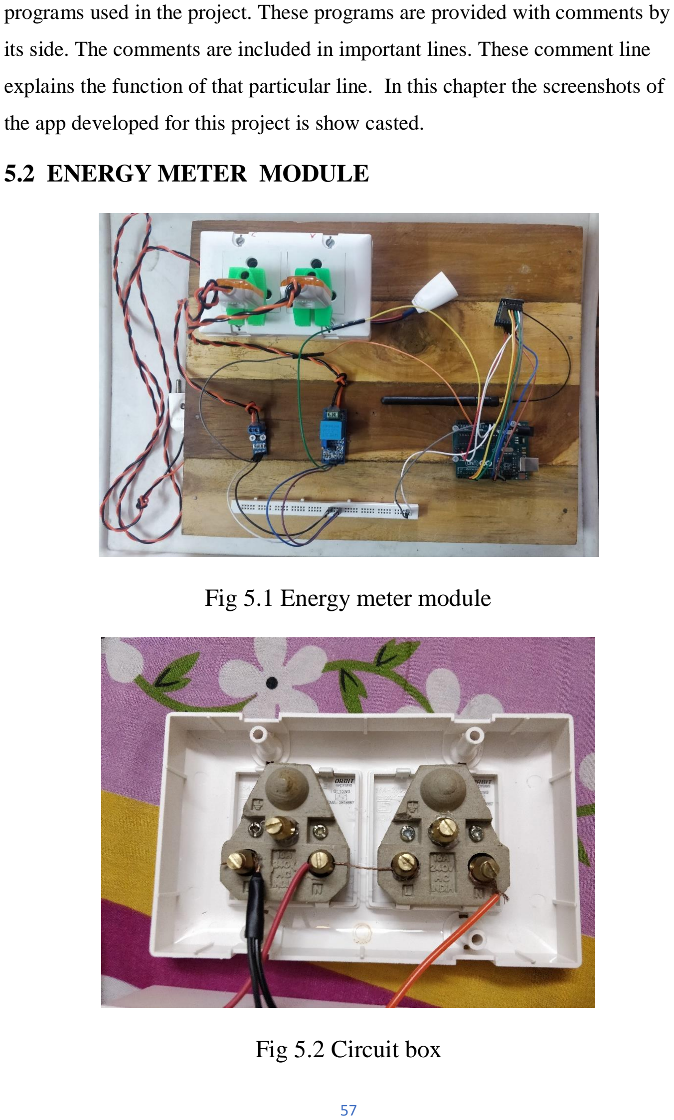
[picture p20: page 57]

programs used in the project. These programs are provided with comments by

its side. The comments are included in important lines. These comment line

explains the function of that particular line. In this chapter the screenshots of

the app developed for this project is show casted.

### 5.2 ENERGY METER MODULE

Fig 5.1 Energy meter module

Fig 5.2 Circuit box

The components are mounted on a solid wooden slab. The switch

box connection is given as specified in the fig.5.2.2. This connection provides

current transformer (CT) and voltage transformer (VT) to get connected across

the load serially and parallelly. The Arduino Uno is screwed up with the wooden

slab. Bread board is stuck to the wooden slab which acts as the junction for the

sensors and Arduino Uno’s 5V and Gnd. LoRa is connected to the Arduino Uno

using jumper wires with SPI interface.

### 5.3 LoRa GATEWAY MODULE

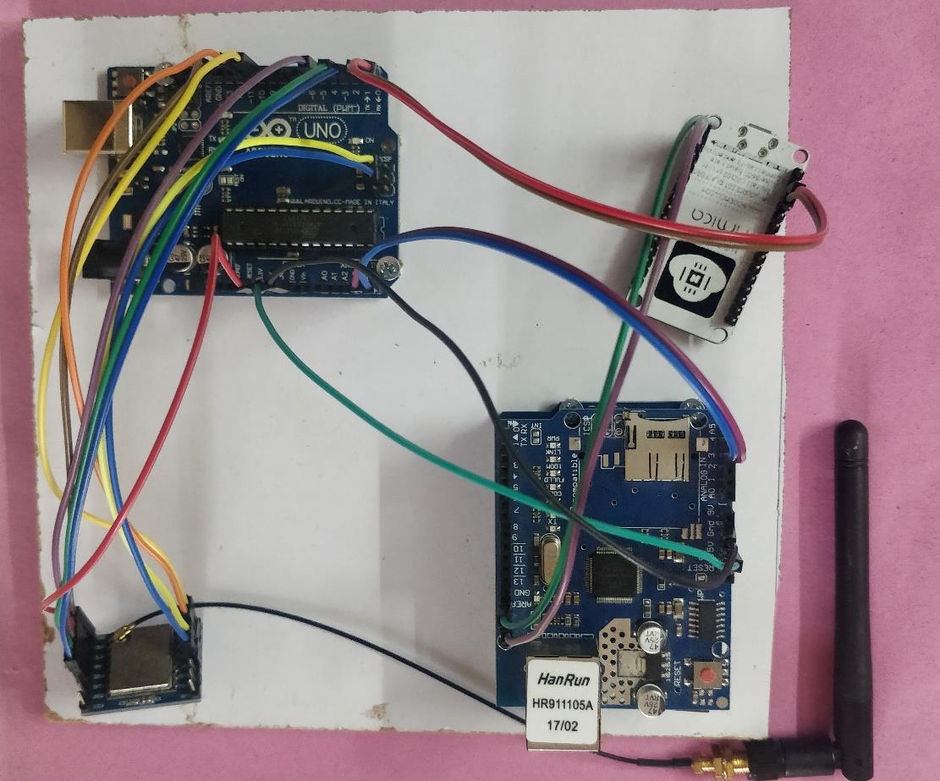
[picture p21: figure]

Fig 5.3 LoRa gateway module

In this setup two Arduino Uno are screwed up on cardboard. One of

which is mounted with ethernet shield, while the other is connected to LoRa.

Node MCU ESP8266 is also mounted on the cardboard. The node MCU ESP8266

is connected to the LoRa receiver Arduino and ethernet shield is also connected

to the Arduino.

### 5.4 FINAL CONCLUSION

The project can be implemented in smart cities as well as it can be

used in remote rural areas. Since it doesn’t use any telecom services the data

transfer cost is minimised. Even though building up LoRa gateway architecture

is expensive it allows data flow to happen at minimal cost. This project will help

to reduce man power by atomizing energy meter. The project has further more

applications in future, as an alternative for GPS. This project is more cost

effective than GSM based smart meter. Through this project the illegal tapping

can be detected at a particular location where it happens. The wattmeter reading

is sent to the EB server directly which makes documentation process more

flexible and transparent. An mobile application is developed for the project which

helps the consumer to view the wattmeter reading in their mobile app in real time.

Since the documentation is digitalized the big data analysis can be run over the

consumer power usage in various circumstances. This helps the Electricity Board

to predict the power requirements in future and plan accordingly. Since the

complete process is so flexible and transparent it avoids bribery to happen.

## CHAPTER 6

REFERENCE

### 6.1 Reference

[1].Visalatchi Senthilnathan , Kamal Sandeep Karreddula for | Smart energy
metering and power theft control using arduino & GSM, | 2017 2nd
International Conference for Convergence in Technology (I2CT),. (https://ieeexplore.ieee.org/xpl/mostRecentIssue.jsp?punumber=8168943)
Electronic ISBN: 978-1-5090-4307-1, Print on Demand(PoD) ISBN: 978-1-5090-4308-8
[2] .Gunawan Wibisono, Gilang Permata Saktiaji, Ihsan Ibrahim for Techno economic analysis of smart meter reading implementation in PLN Bali using
LoRa technology,. | 2017 International Conference on Broadband
Communication, Wireless Sensors and Powering (BCWSP), (https://ieeexplore.ieee.org/xpl/mostRecentIssue.jsp?punumber=8264985) Electronic
ISBN: 978-1-5386-2833-1, Print on Demand(PoD) ISBN: 978-1-5386-2834-8

[3]. Tian Xia ; (https://ieeexplore.ieee.org/author/37086562442) Cencen Liu ; (https://ieeexplore.ieee.org/author/37086563640) Xin Zheng ; (https://ieeexplore.ieee.org/author/37086557094) Ming Lei ; (https://ieeexplore.ieee.org/author/37086555833) Shangpeng
Wang ; (https://ieeexplore.ieee.org/author/37086560597) Yingchun Wang,. (https://ieeexplore.ieee.org/author/37086560953) Research on Field Testing Method of Digital Energy Meters Based on Digital Reference Meter with High Accuracy, 2018 2nd IEEE Conference on Energy Internet and Energy System Integration (EI2), (https://ieeexplore.ieee.org/xpl/mostRecentIssue.jsp?punumber=8564458) Electronic ISBN: 978-1-5386-8549-5

[4]. Win Hlaing ; (https://ieeexplore.ieee.org/author/37086219197) Somchai Thepphaeng ; (https://ieeexplore.ieee.org/author/37071208000) Varunyou Nontaboot ; (https://ieeexplore.ieee.org/author/37086216367) Natthanan Tangsunantham ; (https://ieeexplore.ieee.org/author/37071583900) Tanayoot Sangsuwan ; (https://ieeexplore.ieee.org/author/37085398100) Chaiyod Pira,. (https://ieeexplore.ieee.org/author/37086223524) Implementation of
WiFi-based single phase smart meter for Internet of Things, | 2017
International Electrical Engineering Congress (iEECON), (https://ieeexplore.ieee.org/xpl/mostRecentIssue.jsp?punumber=8053867) Electronic
ISBN: 978-1-5090-4666-9

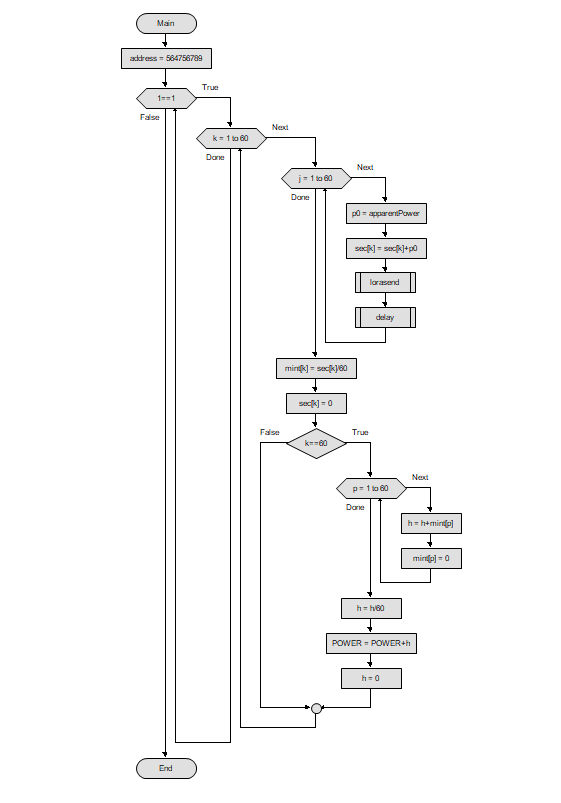
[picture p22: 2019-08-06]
flowchart/flowchart picture/LoRa based smart meter.png

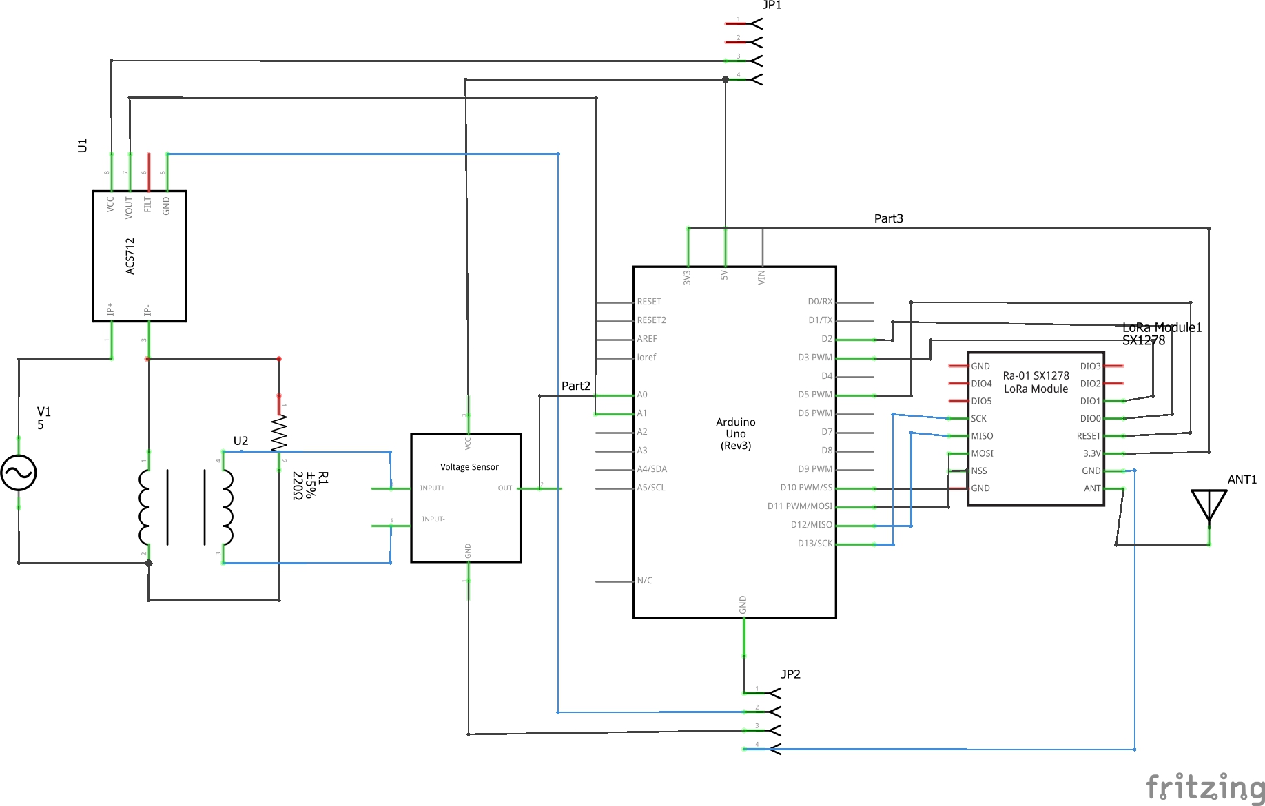
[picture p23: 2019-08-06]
schimatics/schimatics picture/Lora based smart meter.jpg

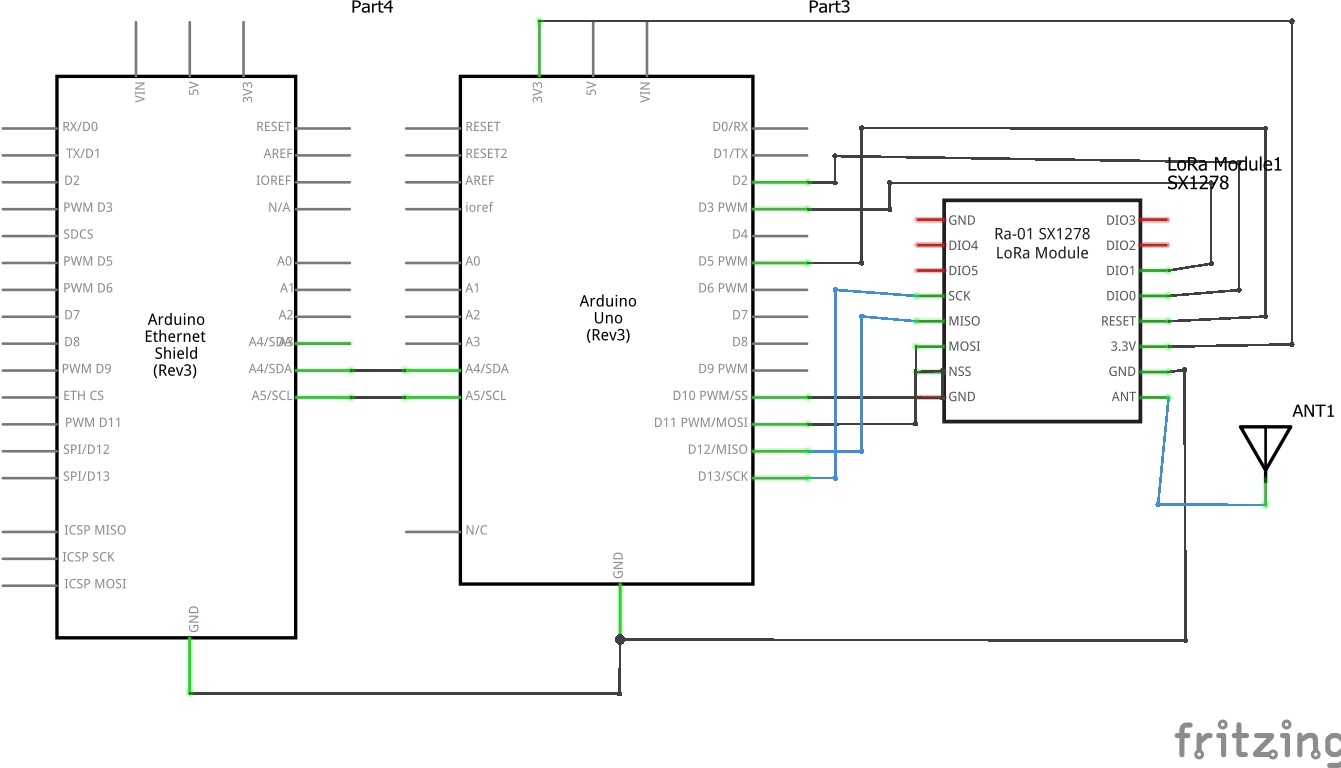
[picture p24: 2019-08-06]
schimatics/schimatics picture/LoRa gateway with eithernet.jpg

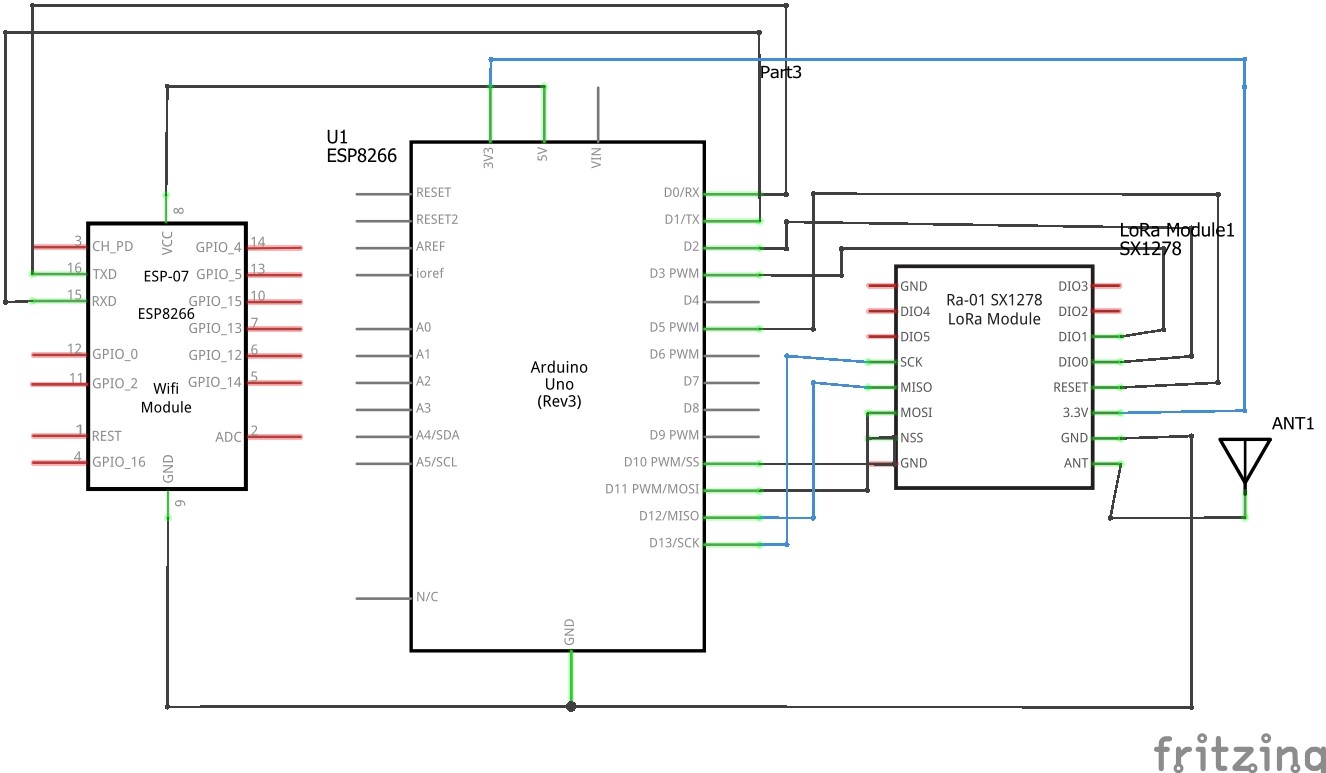
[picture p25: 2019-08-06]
schimatics/schimatics picture/LoRa gateway with wifi.jpg

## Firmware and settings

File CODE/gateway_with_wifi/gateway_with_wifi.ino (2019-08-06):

/*************************************************************
  Download latest Blynk library here:
    https://github.com/blynkkk/blynk-library/releases/latest

  Blynk is a platform with iOS and Android apps to control
  Arduino, Raspberry Pi and the likes over the Internet.
  You can easily build graphic interfaces for all your
  projects by simply dragging and dropping widgets.

    Downloads, docs, tutorials: http://www.blynk.cc
    Sketch generator:           http://examples.blynk.cc
    Blynk community:            http://community.blynk.cc
    Follow us:                  http://www.fb.com/blynkapp
                                http://twitter.com/blynk_app

  Blynk library is licensed under MIT license
  This example code is in public domain.

 *************************************************************
  This example runs directly on NodeMCU.

  Note: This requires ESP8266 support package:
    https://github.com/esp8266/Arduino

  Please be sure to select the right NodeMCU module
  in the Tools -> Board menu!

  For advanced settings please follow ESP examples :
   - ESP8266_Standalone_Manual_IP.ino
   - ESP8266_Standalone_SmartConfig.ino
   - ESP8266_Standalone_SSL.ino

  Change WiFi ssid, pass, and Blynk auth token to run :)
  Feel free to apply it to any other example. It's simple!
 *************************************************************/

/* Comment this out to disable prints and save space */
#define BLYNK_PRINT Serial


#include <ESP8266WiFi.h>
#include <BlynkSimpleEsp8266.h>
char My_String[30];
int String_Length,flag1,flag2,Address_Index,Watt_Index,Power_Index;
char Address[30],Watt_Per_Second[30],Total_Power[30];
BlynkTimer timer;
// You should get Auth Token in the Blynk App.
// Go to the Project Settings (nut icon).
char auth[] = "9c0f15fc9db146f19808881e9fdc4611";



// Your WiFi credentials.
// Set password to "" for open networks.
char ssid[] = "lone";
char pass[] = "neticui4cu";
void sendSensor()
{

 Blynk.virtualWrite(V0,564756789);

 Blynk.virtualWrite(V1,Watt_Per_Second);

 Blynk.virtualWrite(V2,Total_Power);

}

void setup()
{
  // Debug console
  Serial.begin(9600);

  Blynk.begin(auth, ssid, pass);
    timer.setInterval(1000L, sendSensor);
  // You can also specify server:
  //Blynk.begin(auth, ssid, pass, "blynk-cloud.com", 80);
  //Blynk.begin(auth, ssid, pass, IPAddress(192,168,1,100), 8080);
}

void loop()
{
  Blynk.run();
   timer.run();
   Serial.readBytes(My_String,20); //Read the serial data and store in var
   String_Length=strlen(My_String);
   Address_Index=0;Watt_Index=0;Power_Index=0;flag1=0;flag2=0;
  // if(My_String[0]=='+')
   for( int i=0;i<String_Length;i++)
   {
    if(My_String[i]=='$')
    {
      flag1=1;
      continue;
    }
    if(My_String[i]=='=')
    {
      flag2=1;
       continue;
      }
      if(flag1==0&&flag2==0)
      {
        if(My_String[i]=='+')
        continue;
        Address[Address_Index++]=My_String[i];
        }
        else if(flag1==1&&flag2==0)
        {
          Watt_Per_Second[Watt_Index++]=My_String[i];
        }
        else if(flag1==1&&flag2==1)
        {
        Total_Power[Power_Index++]=My_String[i];
        }

        }

  Serial.println(My_String); //Print data on Serial Monitor
  Serial.println(Address);
  Serial.println(Watt_Per_Second);
  Serial.println(Total_Power);

}

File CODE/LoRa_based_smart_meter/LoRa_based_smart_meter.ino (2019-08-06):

#include <SPI.h> // arduino spi library

#include <LoRa.h> // arduino libraries ra02 lora

#include "EmonLib.h"             // Include Emon Library

EnergyMonitor emon1;             // Create an instance

float Watt_per_Second = 0, Watt_per_Hour = 0, Total_Power = 0;

int f = 0, Counter = 0;

char Address[10] = "56788747";

void setup()
{
  Serial.begin(9600);

  emon1.voltage(0, 380, 1.7);  // Voltage: input pin, calibration, phase_shift

  emon1.current(1, 10.8);       // Current: input pin, calibration.

  while (!Serial);

  Serial.println("LoRa Sender");

  if (!LoRa.begin(433E6)) {

    Serial.println("Starting LoRa failed!");

    while (1);

  }

  LoRa.setSpreadingFactor(10);

  LoRa.setSignalBandwidth(62.5E3);

  LoRa.crc();// put your setup code here, to run once:

}

void loop() {


  emon1.calcVI(20, 2000);

  float Watt_per_Second   = emon1.apparentPower;

  Watt_per_Hour = Watt_per_Second / 3600;

  Total_Power = Total_Power + Watt_per_Hour;

  LoRa.beginPacket();

  LoRa.print('+');

  LoRa.print(Address);

  LoRa.print('$');

  LoRa.print(Watt_per_Second);

  LoRa.print('=');

  LoRa.print(Total_Power);

  LoRa.endPacket();

  Counter++;
  ////////////
  // DELAY  //
  ////////////
  if (f == 0)
  {
    delay(601);
  }
  else
  {
    delay(592);
    f = 0;
  }

}
